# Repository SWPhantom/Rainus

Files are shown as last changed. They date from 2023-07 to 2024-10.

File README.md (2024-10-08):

# Rainus
Measure rain in exotic places, remote locations, away from power sources and civilization!

This frankenstein of easy-to-purchase devices lets you log rainfall data to an SD card.  
It efficiently runs off a battery and can store as much logging data as the storage you bequeath it.

This repo contains:
* Arduino code for the ESP32 C3 TTGO T-OI PLUS ESP32-C3 board
* Devlog of the project
* TODO: Posterity Images, etc

Example output data from the field-test Rainus device (headers and notes added for exaplnation):  
[Google Sheets](https://docs.google.com/spreadsheets/d/1Qej0Jb0RguejD68-Whe8UmjqHHGkIUU_zKdhaDspYHQ)

Currently, this is designed to work with a [rain gauge like this](https://www.scientificsales.com/6466-Davis-AeroCone-Rain-Gauge-with-Mountable-Base-p/6466.htm)
Essentially, it's a device that closes a circuit. The ones we currently have use an RJ12 6p6c connector, and the Rainus is (unfortunately) built around it. 

Generally speaking, though, the Rainus Does A Thing when a circuit is closed.

## Setup
1. Follow the setup steps on the (LilyGO Github page for the T-OI-PLUS board)[https://github.com/Xinyuan-LilyGO/LilyGo-T-OI-PLUS]
1. Connect a Rainus to the computer with a USB-C cable (make sure it can transfer data... many don't...)
1. If using ArduinoIDE, open the Serial Monitor and set the BAUD rate to 9600
1. At the top, select a `wusb...` entry in the connected devices and set the device to `TTGO T-OI PLUS RISC-V ESP32-C3`
1. To compile the sketch you will need to add/install 2 libraries: RTClib, DHT20 
1. Upload the Rainus.ino file and look at the Serial Monitor. You should see Rainus chatter!

### Notes
* INFO: For accurate time logging, make sure the TIMEZONE_OFFSET is set to a value that makes sense.
For example, if I'm at PST-0700, I need to set the offset at -7
The RTC keys off of the compile time of the sketch, which doesn't know about timezones, and assumes that the current datetime (local time) is actually UTC time...
Not sure of a way to automatically correct for this yet.

* WARNING: The Grove connector on the Lilygo D1 Plus is wired incorrectly. If you're using a Standard grove-grove cable, you MUST modify the side of the cable that enters the Lilygo.
Sensor side:                  Lilygo side:
black                         white
red                           yellow
white                         red
yellow                        black
Failing to do this, or plugging the two sides into the wrong ports will short stuff on either board. I hadn't seen anything fail, but after getting stung from the heat when touching the boards, I quickly unplugged things. YMMW

### Steps of Operation
* An external device connects VCC to a pin.
* Rainus wakes up from a deep sleep
* Checks if the SD card is present and accessible
* Checks if the RTC is present and accessible
* Reads from sensors, if attached/available
* Writes a log to SD card with:

chipId, timestamp (UTC), unixtime, secondstime, temp (C), humidity (%)
Example: 7598744,2022-09-19T16:11:03,1663603863,716919063

## Rainus 1.0
Parts soldered onto a hand-etched PCB. Single board, stuffed into a cheap, plastic food container.
8 units deployed to Thailand!

A 16340 battery and SD card are replaced on a schedule, where our Thai cave-master, Nong, treks to the Rainuses, opens up the sandwich box, and replaces the battery and SD card in-situ.

There are problems with Rainus 1.0:
* Excess moisture in the caves seems to be shorting traces, draining the main 16340 battery, and maybe draining the RTC coincell battery.
* Replacing the SD card and battery in a cave environment is fiddly work.

## Rainus 2.1 (Deprecated)
Several upgrades over 1.0:
* Increased battery: 18650 batteries are larger, seemingly more ubiquitous, and less likely to be sold under false pretenses...
* Waterproofing via [Silicone Conformal Coating](https://www.amazon.com/gp/product/B085G42TGS)
* PCB designed in KiCad, and manufactured through jlcpcb

This version of the Rainus is split into two sections:
The Mother unit and the Child unit.

The Mother has the ESP32 board and the RTC, which keeps the time. It also has female RJ12 and RJ45 ports to connect to the rain gauge and the Child, respectively. The child is enclosed in a non-waterproof box, with incoming cables going through a hot-glued (or equivalent) slit in the box. 

The Child has the SD card reader with SD card and the battery. It has a single RJ45 port that connects to the Mother. The Child is enclosed in a waterproof box, with an ethernet cable that goes through a gasket-sealed port.

The ethernet cable coming out of the Child goes into a waterproof Ethernet coupler. Another ethernet cable connects to the other side of said coupler and connects to the Mother. 

The intent is for our Cave Technician to come to the Rainus device with a replacement Child box (with a recharged battery and empty SD Card), disconnect the waterproof ethernet coupler between the current Mother and Child, and replace the old Child with the new Child, and reconnect the boxes. The old child will then be taken to a controlled location (without cave moisture...), and the battery and SD card will be taken out and processed.

A Grove moisture/temperature sensor may be added to the Mother unit. Waiting for deliveries from Seeed now.

There are problems with the Rainus 2.1:
* Separate units, connections between units, etc are more costly.
* Multiple units are more bulky to ship.
* If we change the RJ12 plug coming out of the rain gauge to two plugs that can be plugged into waterproof ports on a box, we don't have to worry about moisture and greatly simplify the Rainus design.
* COST.

Current transient problem:
* When the Child unit is disconnected (or the battery removed), the RTC doesn't swap to its coincell battery quickly enough. I saw on some forums that this can be solved by adding an `rc network` to the VCC input, to allow the RTC to switch between the VCC to battery. I'll need to redisign the PCB to have that.
* Though most parts of the boards are covered in silicone, the USB-C port is not. This may be problematic still. May need to stuff the port with a rubber thing. We shall see!

## Rainus 2.2
Back to a single-board design!
Board designed to fit into a [plastic enclosure with a gasket](https://www.amazon.com/dp/B07RTYYHK7).
Two copper wires stick through the enclosure and act as terminals to connect the rain gauge wires to (soldered to alligator clips).
A grove connector and temperature/humidity sensor also sticks through the enclosure to read the environment around the unit.

## Bill of Materials
* LILYGO® TTGO T-OI PLUS RISC-V ESP32-C3
[Aliexpress](https://www.aliexpress.us/item/3256803168396369.html)  
[Github](https://github.com/Xinyuan-LilyGO/LilyGo-T-OI-PLUS)

* PCF8523 RTC
We ended up using a Raspberry Pi-style header PCF8523 RTC. This was ONLY due to shipping availability and price at the time.  
Using a more sane pin style would have made some of the PCB design nicer
[Amazon](https://www.amazon.com/dp/B072DWKDW9)

[What we Should(??) have used](https://a.co/d/cd6rMIO)

* MicroSD Reader/Writer
Bought a couple different ones. These worked right away and came with pin headers, which were great. Small footprint, also good.
[Amazon](https://www.amazon.com/dp/B08CMLG4D6)

There are SD card readers with a nice spring detent, that are bigger.  
Those, however, didn't work and would not be recognized as working SPI devices.

* MicroSD Cards
32GB microSD cards. Bought the cheapest ones that had an appreciable capacity.
[Amazon](https://www.amazon.com/dp/B07RVFZ3F3)

* Perfboards/PCBs/etc
JLCPCB-manufactured PCBs to mount our breakout boards on.

This is a collaboration with [George](https://github.com/kxygk), in order to help with his Monsoon PhD research in Thailand.

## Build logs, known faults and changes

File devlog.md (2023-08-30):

2022-09-16 15 48
GK and I both have our Arduino IDEs writing to the TTGO DOI Plus

Trying to get the SD card writer/reader to work. Using PulseView to debug which pins are used for the SPI protocol.

References:
SD Card
https://randomnerdtutorials.com/esp32-microsd-card-arduino/
https://github.com/Xinyuan-LilyGO/LilyGo-T-OI-PLUS/blob/main/schematic/T-OI_PLUS_Schematic.pdf
https://itp.nyu.edu/physcomp/labs/labs-serial-communication/lab-data-logging-with-an-sd-card-reader-using-spi-communication/
https://docs.espressif.com/projects/esp-idf/en/latest/esp32c3/api-reference/peripherals/spi_master.html

ESP32C3/TTGO T-IO
https://github.com/Xinyuan-LilyGO/LilyGo-T-OI-PLUS
https://github.com/Xinyuan-LilyGO/LilyGo-T-OI-PLUS/blob/main/schematic/T-OI_PLUS_Schematic.pdf
https://www.studiopieters.nl/esp32-c3-pinout/

I2C/RTC
https://create.arduino.cc/projecthub/electropeak/interfacing-ds1307-rtc-module-with-arduino-make-a-reminder-08cb61

Deep Sleep
https://docs.espressif.com/projects/esp-idf/en/latest/esp32/api-reference/system/sleep_modes.html

GK:
Getting the board to be flashed was problematic.
Did NOT install drivers.

Added gk to the dialout group in Linux. 
Added read/write perms to ttyusb0.
  Noticed that the first time the device was plugged in, it routed to ttyusb0. BUT second time it was connected, it was routed to ttyacm0 device.
Added read/write perms to ttyacm0 as well.

Confusing part was the extra remapping to acm0

2022-09-17 00 42
Much blood was spilt

SD card is read and written to.
I did REALLY well. I DESERVE a shake. Denny's??
It IS open right now.

Lessons learned:
File names need leading slashes. Files need to be closed to be saved.
GK adapted some example code into other code.
vspd->fspd in one example, then use the spi init code in an SD example code.

We had issues with pins.
2, 4, 5, 6 for MISO, MOSI, CLK, SS respectively seemed to work.
Plugged the board into breadboard, to break out into the SD reader and the logic analyzer was a good move. Analyzer claws are neat, but finicky.

We took a walk. It helped (maybe).

Checkpoint: Can write files to SD card now.
Next, need to get the other SD card reader working (MAYBE)
REALLY next, need to work on the RTC integration.

Then, button press to get out of sleep, do the reading and writing, and done.

2022-09-17 11 21
Waking up.

Light day today- looking at RTC usage, then temp/humidity sensor, to finish implementation tomorrow.

Woe is us!
Writing to the file in the loop results in an empty file.

Reverting to only writing to the file in the setup function works.

Found the issue- we were opening the file even after we were done. No corruption, but the file was blanked.

Solution: FILE_APPEND
    txtFile = SD.open(filename, FILE_APPEND);

vs
    txtFile = SD.open(filename, FILE_WRITE);

as per
https://forum.arduino.cc/t/appending-datas-to-file-instead-of-recreating-the-file-w-sd-h-library/467651/9

2022-09-18 13 07
Got the I2C RTC working using 
https://create.arduino.cc/projecthub/electropeak/interfacing-ds1307-rtc-module-with-arduino-make-a-reminder-08cb61
Had to initialize the RTC and start its running with
  rtc.adjust(DateTime(F(__DATE__), F(__TIME__)));

2022-09-19 00 13
Checkpoint message. Refactored code to be neat.
We now log the times cleanly, along with the ID of the chip.

2022-09-19 00 44
Starting to add button functionality.

2022-09-19 01 09
Finished button functionality.
Next up, deep sleep!

Temp/Humidity later.
Ordered other RTCs, also

2022-09-19 14 28
Starting deep sleep work
Thinking about too many clicks too fast, of using an exponential backoff, etc

16 18
Done with deep sleep
Added todos. Added debug printing switch.
Did a few 4 17 button presess
1x 4 18
2x 4 21
1x 4 22
3x 4 27 (see 6)
4x 5 37 (see 8, with 2 clicks at 5 36)
6x 5 58 (see 11)
reset at 5 58
3x 5 58 (SEE 4 (could be... 3)

Will come back later to do more

TODO:
* Hook up battery to terminals, see if we get ok 5v power. If so, no need to stress over RTCs
* String concatenation instead of 12 prints to file.
* Cases for different part removal in the field (battery, SD card, etc)
* remap pins for optimal placement of SD card, RTC
* Ideate on case/fixturing
** temperature/humidity

2022-09-19 18 03
Tested the program over time. Need to add logic where the logger:
Wakes up on rain gauge button press, logs data, waits until the button is NOT pressed again, THEN goes to sleep.

Another test, after debounce logic:
3x 6 16
5x 6 17
hold @ 6 33
12x 6 34

Worked!
Holding worked well, all data looks a-ok:
```
7598744,2022-09-19T18:16:45,1663611405,716926605
7598744,2022-09-19T18:16:46,1663611406,716926606
7598744,2022-09-19T18:16:46,1663611406,716926606
7598744,2022-09-19T18:17:06,1663611426,716926626
7598744,2022-09-19T18:17:06,1663611426,716926626
7598744,2022-09-19T18:17:06,1663611426,716926626
7598744,2022-09-19T18:17:06,1663611426,716926626
7598744,2022-09-19T18:17:07,1663611427,716926627
7598744,2022-09-19T18:33:48,1663612428,716927628
7598744,2022-09-19T18:34:19,1663612459,716927659
7598744,2022-09-19T18:34:20,1663612460,716927660
7598744,2022-09-19T18:34:20,1663612460,716927660
7598744,2022-09-19T18:34:20,1663612460,716927660
7598744,2022-09-19T18:34:21,1663612461,716927661
7598744,2022-09-19T18:34:21,1663612461,716927661
7598744,2022-09-19T18:34:21,1663612461,716927661
7598744,2022-09-19T18:34:22,1663612462,716927662
7598744,2022-09-19T18:34:22,1663612462,716927662
7598744,2022-09-19T18:34:22,1663612462,716927662
7598744,2022-09-19T18:34:23,1663612463,716927663
7598744,2022-09-19T18:34:23,1663612463,716927663
```

18 39
String concat?

2022-09-20 0101
No string concat.

GK and I built different versions of the assembly. We reassigned pins to connect the SD card reader directly. 
Looks very good and shoddy at the same time.

We have a cluster of wires soldered to a header pin. Not pretty. Could use the battery negative terminal or something.

TODO:
We may need to disable the wifi and bluetooth.

01 10
Let's measure voltage of battery. 

01 14:
Voltage: 4.13-4.14v

2022-09-20 10 51:
Voltage: 4.12-4.13v

Did 10 readings.

2022-09-20 17 01:
Did a score of more readings
Voltage: 4.11-4.12v

2022-09-27
Tested and added code to make the Arduino RTC work
  RTC_PCF8523 (https://learn.adafruit.com/adafruit-pcf8523-real-time-clock/rtc-with-arduino)

2022-11-16 14:40:00
Just discovered that the local test Rainus is no longer glowing with the on LED.
As I assumed when I put in a non-spec 3v Energizer Lithium 12-2032, when voltage dipped below some threshold, the board shut down.
This must have hapened between November 9th (the last time I pulled data from the card, when the light was still on), and today.
Since I put the device outdoors on approximately October 19th (judging by the first data in [the spreadsheet](https://docs.google.com/spreadsheets/d/1Qej0Jb0RguejD68-Whe8UmjqHHGkIUU_zKdhaDspYHQ/), this shows that with a 3v non-spec battery, the device will work at LEAST 21 days straight, up to 28 days, assuming the battery went below the threshold today...

Let it be known that I put an [in-spec 16340 battery](https://www.amazon.com/16340-Battery-Batteries-2800-Pack/dp/B0BK4KY88J/) into the Rainus device at my house. at the above timestamp

2023-01-01
Some retroactive notes:
The in-spec battery did NOT hold up. Not sure if it was because I didn't charge it or if it was a trash battery at the time.
In fact, I went through two of these batteries and each lasted 1 week or less. I didn't check often, so not sure when the power cut out...

Before going to Thailand to check in on the other Rainus devices and meet with GK on 2022-12-08, I put in the other alkaline Duracell battery (3v rated). THAT one lasted a longer time than the other 16340 batteries. That said, by 2023-01-01, I noticed the battery was dead. 

Another BIG note:
Looking at the previous commit, you'll see that the latest batch of Rainus updates resets time!
This indicates that the line
`if (!rtc.initialized() || rtc.lostPower()) {`
was true and the RTC's time was adjusted to the compile time... which suggests that the RTC battery went below operational theshold...
This doesn't really make sense, and needs to be tested... like immediately. 
GK and I saw similar results in Thailand, though we assumed that the battery drained due moisture shorting.

2023-01-01 17:20:00
Now that I look over the data again, I see that not only did the RTC reset twice in the new dataset, but ALSO that it seems to have reset after I was already gone!
This doesn't seem to make sense. As far as I thought, if the main battery is plugged in, the RTC doesn't reset and ONLY resets if both batteries are out at the same time.

This indicates that my test device needs to go in and a documented, rigorous test should be done:

1. Take out RTC Coin Cell Battery (rtcbat) and 16340 Main Battery (mainbat) 
  - This should set the RTC to unpowered/not started.
2. Turn off the board and put in charged rtcbat and mainbat
3. Connect board to a computer with the latest rainus.ino in Arduino and flash it.
4. Press the rain button a few times over a few minutes.
  - Readings should increment in time as expected.
5. Remove mainbat. Wait a few minutes.
6. Put in mainbat.
7. Press the rain button a few times over a few minutes.
  - Readings should STILL increment in time as expected. Time should NOT have reset.
8. Remove rtcbat. Wait a few minutes.
9. Press the rain button a few times over a few minutes.
  - [ ] Verify what happens here. I expect that the time would have reset on every button press???
10. Put in rtcbat. Wait a few minutes.
11. Press the rain button a few times over a few minutes.
  - [ ] Readings should have reset again, BUT will now increase in time as expected.
12. Remove rtcbat and mainbat. 
13. Put in rtcbat and mainbat.
14. Press the rain button a few times over a few minutes.
  - [ ] Readings should have reset again, and will increase in time as expected.

Further, I'll need to comment out the battery time reset logic. If the RTC's `rtc.lostPower()` is true, it may still carry a memory of the last time???
I'm pretty sure if `rtc.initialized()` is true, the time has been wiped, though.

I should read the specs!

Either way, if the RTC had an issue in time, we should write that to the SD card. 
eg, if lostPower() is true,
```
1642488,2022-10-19T17:29:31,1666200571,719515771
1642488,2022-10-19T17:29:45,1666200585,719515785
LOST POWER. CURRENT TIME: 2022-10-19T17:29:51
```
and keep logging normally. Will need to check if `rtc.start();` needs to be called after that, though.

2023-04-27
Rolled-up update!

We got the blessing to do Rainus2!
Created the loggo project/service that can get arbitrary logs. Making the Rainus devices send HTTP POSTs when testing.

Will be making new versions of the Rainus devices. Alternate chips (non-pi RTC, etc), alternate batteries, added dc-dc converter???

2023-05-06
Soldered all the liligo boards to pins.
Noticed that they are all version 1.3!

Replaced the pi header PCF8523 with the HiLetgo one:
https://www.amazon.com/gp/product/B082LTHR28

Learning to use the Power Profiler Kit II:
https://www.nordicsemi.com/Products/Development-hardware/Power-Profiler-Kit-2

Hooked up Rainus to the PPK2 and found that idle Amp usage:
1-2mA
max spikes to 100mA

With a 2500mAh battery, it would last between 50 and 100 days.

2023-05-11
Ordered first version of boards from JLCPCB:
OrderId: Y1-6005729A

2023-05-17
Boards arrived! Extremely fast shipping. 
Put together one of the prototype boards.
Takeaways/discoveries/todos:
* Make sure the through hole diameters are larger. .6/.7 work, but they're a bit tight for the pins I have.
  * .9mm should be great.
* RJ12/13 connectors do NOT fit into JR45.
  * Order and use JR13 connectors Get the 6 pin 6 position ones.
* I routed the data cables backwards for the SD card reader...
  * Changed the Rainus compile code.
* No ground plane.
  * Rerouted connections and added groundplane.
* Battery power on Mother board awkwardly placed.
  * Routed power directly under the Lilygo's power inputs for short, easy-to-solder connections.
* Corners rounded for next version.
* Improved silkscreen layer
* Replaced/rerouted resistor. Using an 0805/2012 4.7K SMD Resistor
* Separated connections to different layers, to minimize roundabout paths.

2023-05-21
Put together one of the 10 mother/child boards!
Using ethernet cables to connect them.
Manually soldering conductors to through holes. Tedious process. I should use actual Ethernet jacks...

Just deployed the board outside with an 18650 batter that's measuring 4.14V

2023-06-10
Replacing the test rainus battery
Old Battery: 3.97V (.17V drop)
New Battery: 3.92V

2023-06-07
Rainus 1.2 boards ordered.

2023-06-17
Rainus 1.2 boards left LA import facilities! Should be here this week.
Need to try out different containers after a sample board is assembled.

Maybe different containers for the mother and child boards.
Child board is more water-sensitive, due to SD card and battery. I bought
`MAKERELE Wire Strain Relief NPT 3/8”Nylon Cord Grips Cable Glands Cable Gland Joints`
from Amazon, which should keep water ingress minimal with the child board.
I also ordered
`ANMBEST 10PCS M23 Shielded RJ45 Waterproof Cat5/5e/6 8P8C Connector IP67 Ethernet LAN Cable Connector Double Head Outdoor LAN Coupler Adapter Female to Female`
Which are laaarge, but should make the interface between the ethernet cables free from water ingress, too.

Idea will be to have a completely water-resistance child board module, which will consist of

                  __________________
LAN coupler      |child board in box|
==}-------------[|]-¬ ___           |
          strain |  L|   |[===]     |
          relief |   |___|    batt  |
                 |   []sd           |
                 |     card         |
                 |__________________|

I'll make 2x of these than the Rainus main boards, so that these can be swapped out and have their SD cards replaced in a non-wet-cave environment.

I'll have to build the ethernet cables AFTER they go through the strain relief gland, as the male ethernet plug will not fit through...

2023-06-22
Put together a mother board and 2 child boards to test out swapping out the child boards.
Issue found!

Looks like when we disconnect power from the board quickly, the RTC doesn't have enough time to swap power from vcc to battery:
https://www.nxp.com/docs/en/data-sheet/PCF8523.pdf (page 53-54). We should include an "rc network on the vcc pin"... So I need to figure out what that means and how to do it >_>

Furthermore, geokon and I talked about the possibility of simplifying this project by changing the RJ13 cable ffrom the rain gauge to two plugs.
That way, the whole Rainus system can be on a single board again, inside of a waterproof container, and have two connectors resistant to water ingress
to plug the rain gauge wires into.

Need to test how I can do that and how the process can be repeatable.

2023-06-25
[DHT 20 Seeed Temperature/Humidity Grove sensor](https://www.seeedstudio.com/Grove-Temperature-Humidity-Sensor-V2-0-DHT20-p-4967.html) working! The Lilygo board doesn't use the correct layout for its Grove connector, so I had to shift around the crimped wires.

Things to do/think about:
1. Power usage with the new sensor
2. If using sensor, we DO want to expose it to the surroundings. How to do it? Either have a slit in the box with the less-sensitive parts (if keeping the 2-box system)
3. If using sensor, and if sensor is borked, gonna log default -666.0 values for temp and humidity, but otherwise log, cuz it's a secondary measuring thing
4. If using sensor, and using two boxes, probably keep using the rain gauge RJ12 connector
5. If not using sensor, how to connect two separate wires from the gauge to the box in a waterproof way?
6. If using sensor, AND we want to use a single, waterproof box, how to connect SIX separate wires (4 for Grove, 2 for rain gauge) in a waterproof way to box?

2023-07-01
Designed and ordered the v2.2 Rainus boards!

This is what geokon and I decided:
This version of Rainus:
* Contained in one box.
* Made of the following sensors/parts:
ESP32 dev board
SD Card Reader/Writer + SD Card
PCF8523 RTC + CR1220 battery   <-- Modified to have a solder bump on the board's negative battery terminal
Seeedstudio Grove - Temperature & Humidity Sensor V2.0 (DHT20)
18650 Battery Holder + 18650 Battery
4.7k resistor
Rain Gauge
Rain-proof project box (~100X68X50mm)
Wire
* Will have the Temperature/Humidity sensor on the outside of the box, with its wires going through a drilled hole in the box.
* Will have two copper terminals extruding from the box through drilled holes. These are used for the Rain Gauge wires to connect to.
* The holes will be filles with water-proof epoxy/silicone/other sealant.
* The Rain Gauge wire will be stripped and split into two parts, with each soldered to an alligator clip, or similar.
* The battery holder, battery, and SD card will be easily accessible when the box is serviced.

The Rainus box will be wholly replaced when Nong does his rounds. The Rain Gauge's clips will be unclipped from the exposed terminals, the box will be replaced, and the clips will go on the new box's terminals.

The box will be taken to a safe, dry location and will have its 4 screws removed. Then, the 18650 battery and the SD card can be replaced.

2023-07-09
A couple weeks ago, I found Paul Price on youtube: https://www.youtube.com/@paulprice . He has long design and assembly videos for his electronics projects.
Great channel and I've been watching a bunch of his streams to prepare for Rainus 3 work.
On 2023-07-05, he came out with a video: https://www.youtube.com/watch?v=vbtSqaVAqRw
He built a data logger that looks like it matches all our needs!
I talked to him, and got a couple boards to do tests on.
If the Rainus 2.2 boards do not work for this phase of research, the Bee Data Loggers will be a fantastic fallback.
In the future, they'll be great boards to scale up the project.

I will still be designing the Rainus 3 board, but trying to find a niche that doesn't overlap with this board (waste of effort and it'll likely be too expensive, time-wise to just redo that board).
However, a board that matches or improves on the (miniscule) power draw of the Bee Logger, with a simpler power bus, using the small non-antenna ESP32 C3 chips will be a good design and assembly endeavor.

https://github.com/strid3r21, for reference!

2023-07-10
Received Rainus 2.2 boards!

2023-07-11
Desoldered all (-3) Rainus 2.1 boards to get the ESP32 dev boards free. Terrible experience. Needed to use a hot air gun and pry the dev boards off. 

2023-07-12
Had an issue where EVERY ES32 v1.3 board (even the new ones) was not flashing with the following message.
`A fatal error occurred: Unable to verify flash chip connection (No serial data received.)`
Which was weird, as I was actively getting Serial data in the Serial monitor with the boards running.
Searched around, saw that most people said it was a hardware issue. I thought that my desoldering method cooked the ESP32 chips, or the Flash chips.
However, because the new boards were also not flashing, this was unlikely (unless the new boards were shipped bad...?)

Anyway, I later realized that, when connecting the dev boards to my computer and Arduino IDE and selecting a Board and Port, there are 2+ choices for connecting.
Specifically, the USB ports:
* /dev/cu.usbserial-56581020151 Serial Port
* /dev/cu.wchusbserial56581020151 Serial Port // USE THIS ONE FROM NOW ON

In short, the wch... one was the one that DIDN'T give me upload errors.
I could have sworn that for the esp32 v1.2 boards either one worked, but my memory is hazy...

After the relief that the dev boards are a-ok, I put together one Rainus 2.2 board (without waterproofing/drilling the enclosures)

Spent the day touching the gauge terminals together and logging temperature and humidity around my path in Seattle. Looking good so far.

2023-07-13
Water stress-test:
* Put waterproofing silicone on the Rainus 2.2 components and breakout boards
* Drilled holes into the enclosure (two small holes for the rain gauge terminals, and a larger hole for the Grove wires)
* Put J-B Weld Plastic Bonder Epoxy in the egress holes
* Sealed the box and submerged it until water came over the seal and sealed Grove hole
* Attached the Rain Gauge (with wires stripped and soldered to copper alligator clips) to the exposed terminals on the outside of the box
* Set my sink to drip water into the Rain Gauge.

2023-07-14
The Rain Gauge activated every 12-14 seconds. 
Started at
0045
Ended at
1122

Approximately 38,220 seconds

That SHOULD be 2940 clicks

The rainLogOvernight.txt shows 2613 logs during that time!
Gonna do some data analysis!

Thoughts/improvements:
* When the Grove sensor is not connected, the Rainus doesn't work, and breaks when trying to initialize it. 
  I'll need to make my own version of the DHT.cpp file. If not initialized, gotta return default values, but let logging keep happening.
* geokon doesn't like the wires attached to the lid. I agree that it's not the best, but I'm thinking about ease of disassembly. Gonna try to run the wires UNDER the board and come out under the box.
* Gotta give the SD reader a little more room with its pins. Current angle makes it less-than-perfect during SD/battery swap.

2023-07-16
Wrote python script to parse rainus output.
Analyzed the drip data and found that the drip rate slowed down throughout the night. The result data looks good!

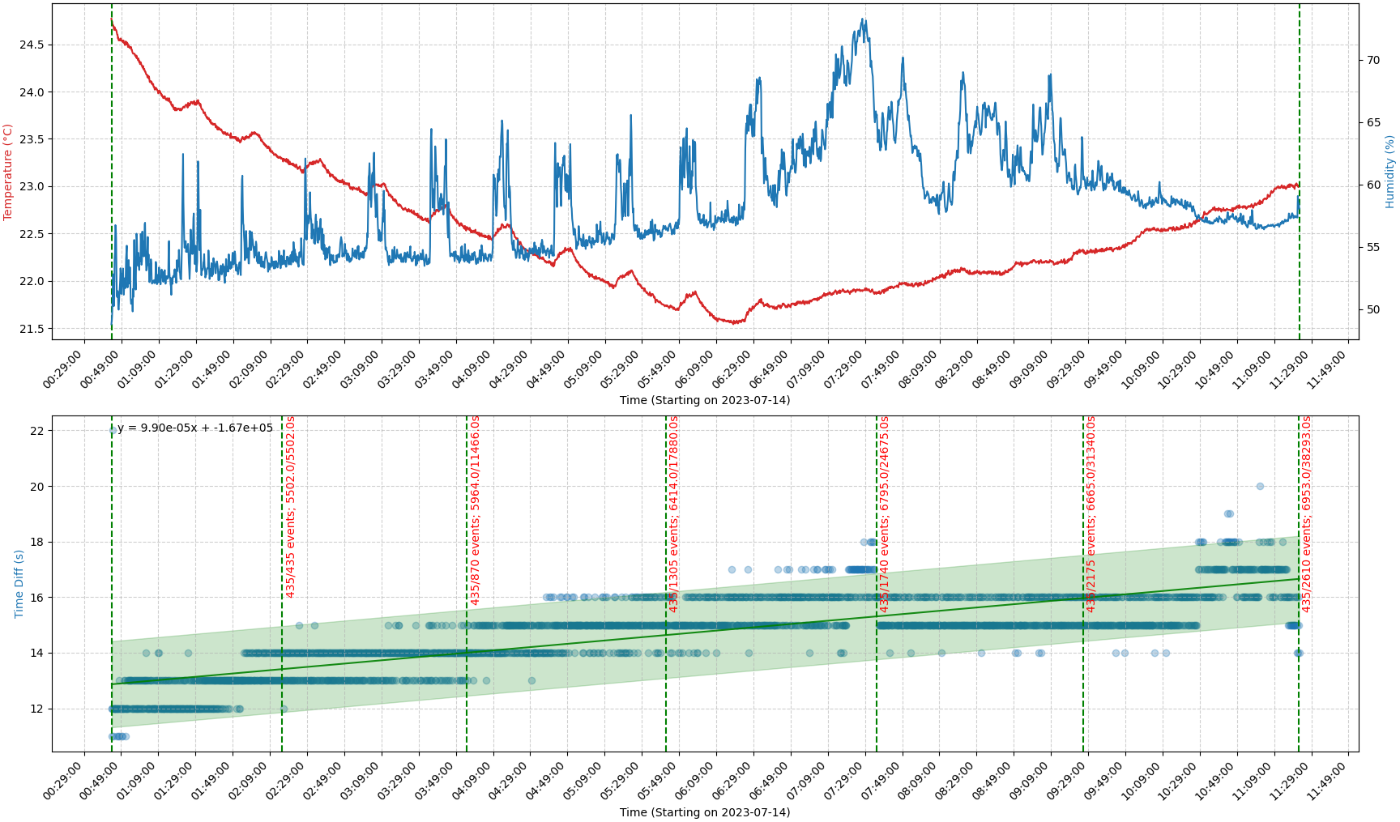
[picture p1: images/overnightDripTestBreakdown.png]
overnight test graph Overnight Drip Test Results


2023-08-14
1st Rainus v2.2 adventures:
Had the same battery in it since 2023-07-12
Currently at 4.07v
Unfortunately... I'm not sure what the battery voltage was exactly when I started, but the other batteries, which had not been plugged in are all between
3.96 to 4.14 (most between 4.01 and 4.08)
That means that the battery, at worst, went down .7 more than the most charged battery.

That SEEMS like good news!
Not sure what the battery cutoff will be for the ESP32 board, but it will LIKELY last for more than 3 months, assuming a well-built battery.

Over that time, we logged about 38000 entries (2.4MB)!

Some days of operation, the Rainus withstood 16 to 47 degrees celcius and rain directly on the outside of the box and temp/humidity sensor!

Still ticking.

One thing to think about is the blackness of the box. If in direct sunlight, it may give weird temperature readings, as the temperature sensor is facing
the top of the box, which probably heats up extra when in direct sunlight. Maybe Rainus boxes meant for outdoor use should have a foil tape taped
under the rain sensor, so as not to heat up from direct sunlight.

Also, waiting for 4 rain gauges to arrive at my house.

My currect Rainus v2.2 status:
1 Complete
2 In Boxes, needing to get programmed
17 Out of boxes, need to have their boxes drilled and sealed, need to get programmed, and may need to have their terminal wires put on backwards,
so that the lid of the box has the sensor and terminals.

Learnings/TODOs
* Putting the terminals and sensor on the bottom side of the box, with wires routed under the circuit board looks nicer, but is a horrible pain to assemble. Pity to the ones that have to take the boards out to program them later...
* Need to order 12 alligator clips to send away to Thailand.
* I ran out of SD card readers! Surprising! But have the perfect amount for the 20 to be sent
* Need to order more SD cards, likely...
* The Grove wires need to be swapped very specifically ESP32-side. Otherwise, the ESP32 board and/or the temperature/humidity sensor gets PROBMEMATICALLY hot...

2023-08-20
Got news a couple days ago that the extra rain gauges are not coming to my house YET. Will see if that resolves soon.

Found a different DHT20 library to use for the temp/humidity sensors: https://github.com/RobTillaart/DHT20
Changed the code to log values if found and log default values if not found.

Found an issue with the RTC time setting... Unfortunately, the compile time is assumed to be UTC, but uses local time. I added a UTC offset in the code so that whoever compiles the sketch will set the RTCs to UTC time. This SHOULDN'T be necessary, now that the units have been set, but needs to be called out.

Cleaned up code. No more web/timer stuff. Hopefully it's a LITTLE cleaner...

2023-08-29
Another check of the battery we've been using in the test unit:
3.89v

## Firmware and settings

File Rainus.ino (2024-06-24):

#include <SD.h>
#include <Wire.h>
#include "RTClib.h"
#include "Arduino.h"
#include "esp_adc_cal.h"

// DHT20 Temperature/Humidity sensor
#define TEMPSENSOR true
#if TEMPSENSOR == true
  #include "DHT20.h"
  DHT20 DHT;
#endif

//// SPI/SD Card section
#define FSPI_MISO   5
#define FSPI_SCLK   6
#define FSPI_MOSI   7
#define FSPI_SS     10

// Rainus log file (Don't forget the leading slash! eg "/rainLog.txt")
const char filename[] = "/rainLog.txt";
File txtFile;

//// External wakeup pin
const int buttonPin = 2;
int buttonState = 0; 
#define BUTTON_PIN_BITMASK 0x000000004 // 2^33 in hex. defines GPIO pin 2

//// Extra bits
uint32_t chipId = 0;

//// RTC/Time/etc
#define RTC_CHECK_COMPILE_TIME true
RTC_PCF8523 rtc; // Adafruit 3.3v RTC (https://learn.adafruit.com/adafruit-pcf8523-real-time-clock/rtc-with-arduino)
DateTime compileTime;
DateTime now;
RTC_DATA_ATTR int bootCount = 0;
int TIMEZONE_OFFSET = -7;

//// Debug/Helpers
#define DEBUG true
void pr(char * input) {
  #if DEBUG == true
    Serial.println(input);
  #endif
}

// Print quick function. If DEBUG is on, pr() will print to serial out.
void pr(StringSumHelper input) {
  #if DEBUG == true
    Serial.println(input);
  #endif
}

void writeLog() {
  vTaskDelay(10);
  now = rtc.now();

  vTaskDelay(10);
  txtFile = SD.open(filename, FILE_APPEND);
  
  // CSV format:
  // chipId, timestamp (UTC), unixtime, secondstime, temp (C), humidity (%)
  // Example: 7598744,2022-09-19T16:11:03,1663603863,716919063
  txtFile.print(chipId);
  txtFile.print(',');
  txtFile.print(now.timestamp());
  txtFile.print(',');
  txtFile.print(now.unixtime());
  txtFile.print(',');
  txtFile.print(now.secondstime());
  #if TEMPSENSOR == true

    vTaskDelay(10);
    // Set default values for the temp/humidity sensor
    float default_value = -666.0;
    float humidity = default_value;
    float temperature = default_value;
    int status = -1;

    // Async request data read, sleep for 80ms, read data, and convert
    status = DHT.requestData();
    delay(80);
    DHT.readData();
    status = DHT.convert();

    // If the DHT read was successful, set the found values. If not, keep the default values
    if (status == DHT20_OK) {
      humidity = DHT.getHumidity();
      temperature = DHT.getTemperature();
    }

    pr("Humidity:");
    pr(humidity);
    pr("Temperature:");
    pr(temperature);

    // Write to log file
    txtFile.print(',');
    txtFile.print(temperature); // Temperature (c)
    txtFile.print(',');
    txtFile.print(humidity); // Humidity
  #endif
  txtFile.println();
  txtFile.close();
}

esp_err_t err;

void setup() {
  setCpuFrequencyMhz(40);

  Serial.begin(9600);
  while (!Serial);
  pr("");
  pr("Start!");

  // Deep sleep wakeup source initialization.
  // This board allows the mask to define pins 0-5, but no others.
  // BUTTON_PIN_BITMASK 0x000000004 // defines GPIO pin 2
  err = esp_deep_sleep_enable_gpio_wakeup(BUTTON_PIN_BITMASK, ESP_GPIO_WAKEUP_GPIO_HIGH);
  if (err != ESP_OK) {
    pr("esp_deep_sleep_enable_gpio_wakeup resulted in error:" + (int)err);
  }

  // initialize the pushbutton pin as an input:
  pinMode(buttonPin, INPUT);
  buttonState = 0;

  // SPI setup for SD card
  SPIClass * fspi = new SPIClass(FSPI);
  fspi->begin(FSPI_SCLK, FSPI_MISO, FSPI_MOSI, FSPI_SS); //SCLK, MISO, MOSI, SS

  // Initialize the SD card
  if (!SD.begin(FSPI_SS, *fspi)) {
    pr("Card failed, or not present");
    // If card isn't found, deep sleep.
    esp_deep_sleep_start();
  } else {
    pr("Card Detected!");
  }

  // Calculate chipId
  for(int i=0; i<17; i=i+8) {
	  chipId |= ((ESP.getEfuseMac() >> (40 - i)) & 0xff) << i;
	}

  //// RTC Setup part!
  // Check if RTC exists
  if (!rtc.begin()) {
    pr("Couldn't find RTC");
    // BROKEN. WE DONE
    esp_deep_sleep_start();
  }

  // Check the compile time of the sketch
  compileTime = DateTime(F(__DATE__), F(__TIME__));
  pr("Compile Date and time:");
  pr(__DATE__);
  pr(__TIME__);

  compileTime = DateTime(compileTime.unixtime() - (TIMEZONE_OFFSET * 60 * 60));
  // Check the time the RTC thinks it is
  pr("Checking PCF8523 RTC.\nCurrentTime:");
  now = rtc.now();
  pr(now.timestamp());

  // If the RTC is not initialized or if the compile time is later than the current chip time, adjust the RTC's clock
  if (!rtc.initialized() || compileTime > now) {
    pr("PCF8523 RTC is NOT initialized, let's set the time!");
    pr("Initializing the RTC...");
    // following line sets the RTC to the date & time this sketch was compiled
    rtc.adjust(compileTime);
    rtc.start();

    pr("...done!");
  }
    
  pr("RTC is running. Datetime:");
  pr(rtc.now().timestamp());

  // Begin the Temperature/Humidity sensor
  #if TEMPSENSOR == true
    DHT.begin();
  #endif
}

esp_sleep_wakeup_cause_t wakeup_reason;

void loop() {
  wakeup_reason = esp_sleep_get_wakeup_cause();

  // If the board woke up from deep sleep via rain gauge/button, we're golden! Time to log!
  if(wakeup_reason == 7) {
    pr("Button has been pressed. Time to LOG.");

    // Log to SD card!
    writeLog();

    // Section to wait until the button is unpressed, to not have bounced signal/logs that happen very quickly.
    do {
      buttonState = digitalRead(buttonPin);
    } while (buttonState == HIGH);
  }

  pr("The time has come for slumber...");
  esp_deep_sleep_start();
  // Program won't get here
}

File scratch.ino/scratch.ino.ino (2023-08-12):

#include <SD.h>
#include <Wire.h>
#include "RTClib.h"
#include "Arduino.h"
#include "esp_adc_cal.h"

#define TEMPSENSOR true
#if TEMPSENSOR == true
  #include "DHT.h"
  #define DHTTYPE DHT20
#endif

//// Debug/Helpers
#define DEBUG true
void pr(char * input) {
  #if DEBUG == true
    Serial.println(input);
  #endif
}



// Print quick function. If DEBUG is on, pr() will print to serial out.
void pr(StringSumHelper input) {
  #if DEBUG == true
    Serial.println(input);
  #endif
}

esp_err_t err;

void setup() {
  setCpuFrequencyMhz(40);

  Serial.begin(9600);
  while (!Serial);
  pr("");
  pr("Start!");

  //// Temperature/Humidity Sensor
  #if TEMPSENSOR == true
    DHT dht(DHTTYPE);
  #endif
  
  // Begin the Temperature/Humidity sensor
  #if TEMPSENSOR == true
    dht.begin();
  #endif

  #if TEMPSENSOR == true
    float temp_hum_val[2] = {0};
    if (!dht.readTempAndHumidity(temp_hum_val)) {
      // Default result is in Celcius
      temp_hum_val[1] = temp_hum_val[1];
    } else {
        temp_hum_val[0] = -666.0;
        temp_hum_val[1] = -666.0;
    }
    pr("Humidity:");
    pr(temp_hum_val[1]);
    pr("Temperature:");
    pr(temp_hum_val[0]);
  #endif
}

void loop() {

  
  
  pr("SENITEE CHEK SHOULD NOT PRINT.");
}

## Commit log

2022-09-19 Added button functionality.
2022-09-19 millisecond estimation for run, deleting unnecessary code, added comments, failure is sleep
    [Rainus.ino]
2022-10-29 Readme work!
    BoM, description, todos
2022-10-29 Create test.csv
    Testing grafana
    [test.csv]
2022-11-16 Update battery info
2023-04-27 April 2023 udpate
    [rainus.kicad_pcb, rainus.kicad_sch]
2023-05-07 pre-power checkpoint
2023-05-10 card reader fix checkpoint
    [Rainus.ino]
2023-05-11 updating kicad
    [rainus.kicad_pcb]
2023-05-11 gerbers files
    [rainus1.0.kicad_pcb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]
2023-06-17 Devlog and pre-rainusv1.2 arrival.
    [rainus2.0-B_Cu.gbl, rainus2.0-B_Mask.gbs, rainus2.0-B_Paste.gbp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]
2023-06-26 Added temp/humidity sensor code
2023-07-02 Updated code and gerbers for v2.2
    [rainus1.0.kicad_pcb, rainus1.1.kicad_pcb, rainus2.1.kicad_pcb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]
2023-07-14 July 14th Update
    [rainus2.2.kicad_pcb]
2023-07-17 deleted files...
    [test.csv]
2023-08-20 Changing DHS library. Safe removal of sensor
2023-08-20 Code cleanup, RTC UTC fix
    [Rainus.ino]
2023-08-30 Fixed compilation error. voltage measure
    [Rainus.ino]
2026-11-09 new nanoCH32v203 v1.1 board integration
2026-11-09 enclosure stuff
2026-11-11 power tests and log updates
